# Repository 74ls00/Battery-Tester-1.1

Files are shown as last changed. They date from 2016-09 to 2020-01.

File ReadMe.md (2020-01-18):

#### Анализатор батареек и аккумуляторов
----
Анализатор батареек и аккумуляторов разрабатывался по заказу одного из импортёров элементов питания и по мотивам статей для Ф-Центра. Задача — измерение ёмкости и оценка качества батареек в разных режимах разряда, с построением детального графика и сохранением всех полученных данных для демонстрации представителям завода-производителя.
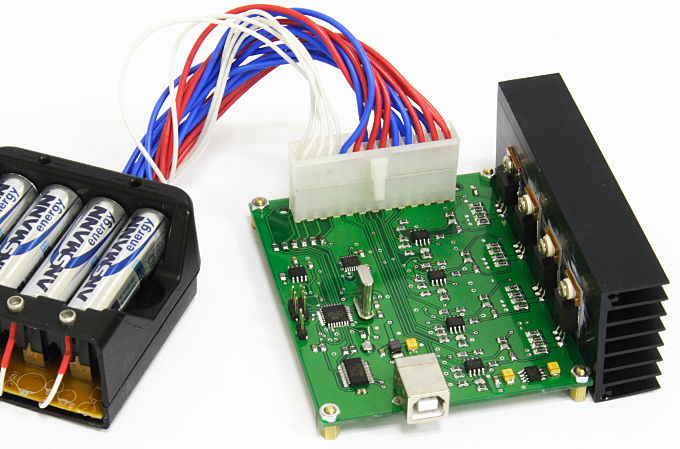
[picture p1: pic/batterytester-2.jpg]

Основные возможности стенда:

- общение с компьютером по USB, полностью программное управление;
- питание от шины USB;
- четыре независимых канала разряда с током 0…3 А каждый и шагом изменения тока 3 мА;
- режимы разряда постоянным током, постоянной мощностью (ток растёт по мере разряда) и на постоянное сопротивление (ток падает по мере разряда);
- режим разряда импульсным током с заданной скважностью;
- любые элементы питания с напряжением до 4,75 В, от батареек до литиевых аккумуляторов;
- 10-битные АЦП и ЦАП;
- индивидуальная калибровка каждого канала по току и напряжению;
- хранение калибровочных параметров в ПЗУ микроконтроллера;
- построение графика напряжения на элементах в реальном времени;
- установка допустимого уровня разряда элементов;
- автоматическое отключение разряженных элементов;
- светодиодная индикация состояния каждого элемента;
- сохранение всех полученных данных в формате CSV;
- автоматический расчёт ёмкости в ампер-часах и ватт-часах, а также внутреннего сопротивления элементов.

Программное обеспечение:

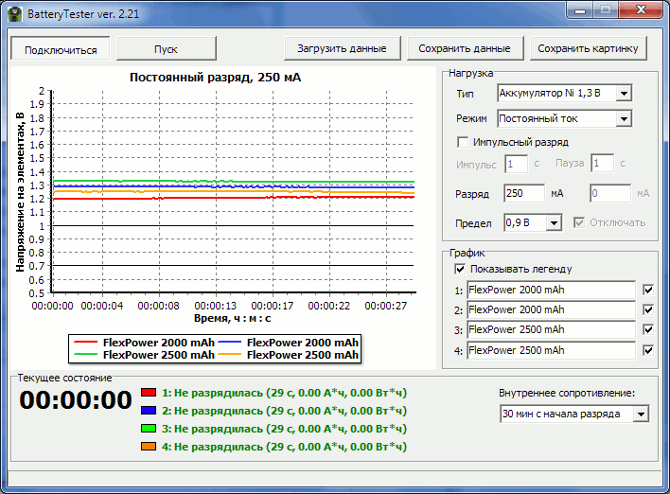
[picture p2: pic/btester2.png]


~~[Страница автора](http://olegart.ru/wordpress/batterytester/)~~

[Тема на коте](http://radiokot.ru/forum/viewtopic.php?f=11&t=135313)

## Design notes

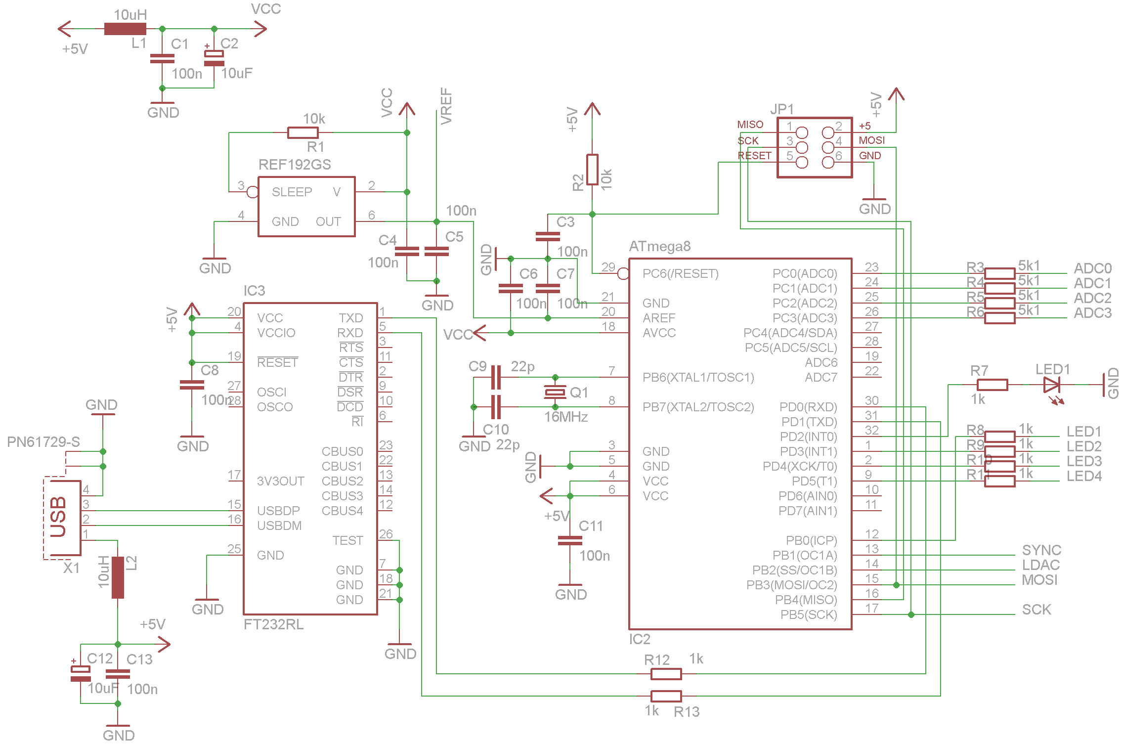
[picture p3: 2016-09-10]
hw/png/100a.png

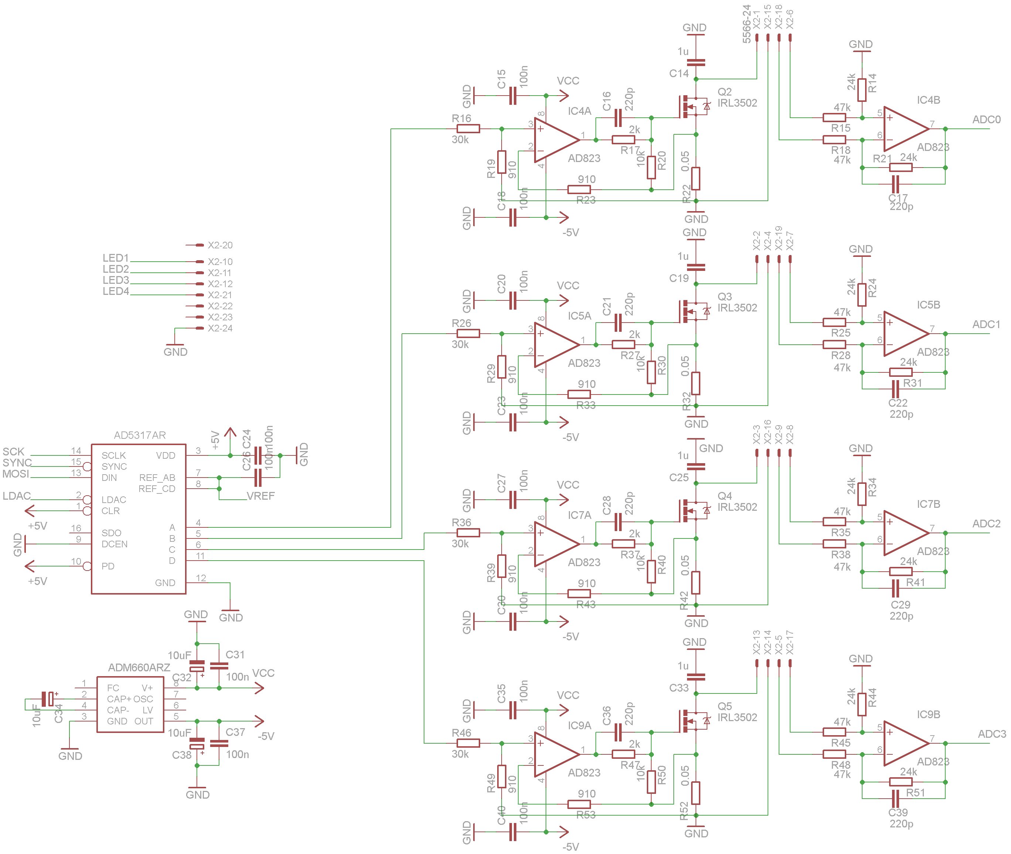
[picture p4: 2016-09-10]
hw/png/100b.png

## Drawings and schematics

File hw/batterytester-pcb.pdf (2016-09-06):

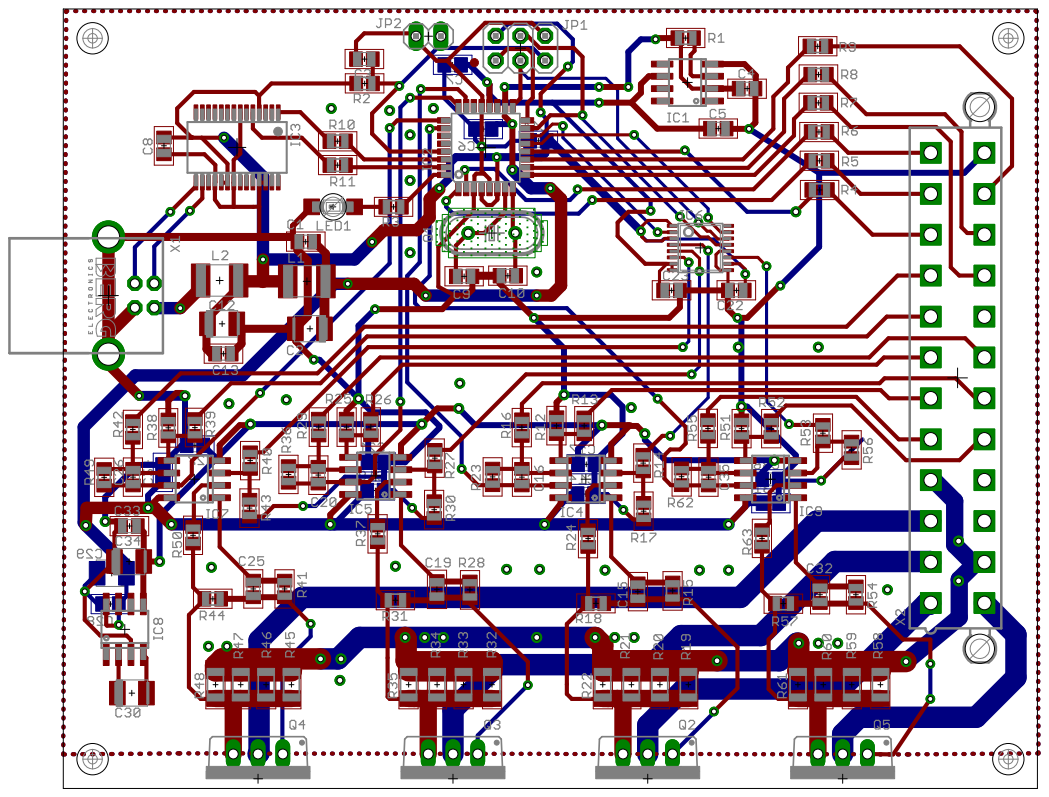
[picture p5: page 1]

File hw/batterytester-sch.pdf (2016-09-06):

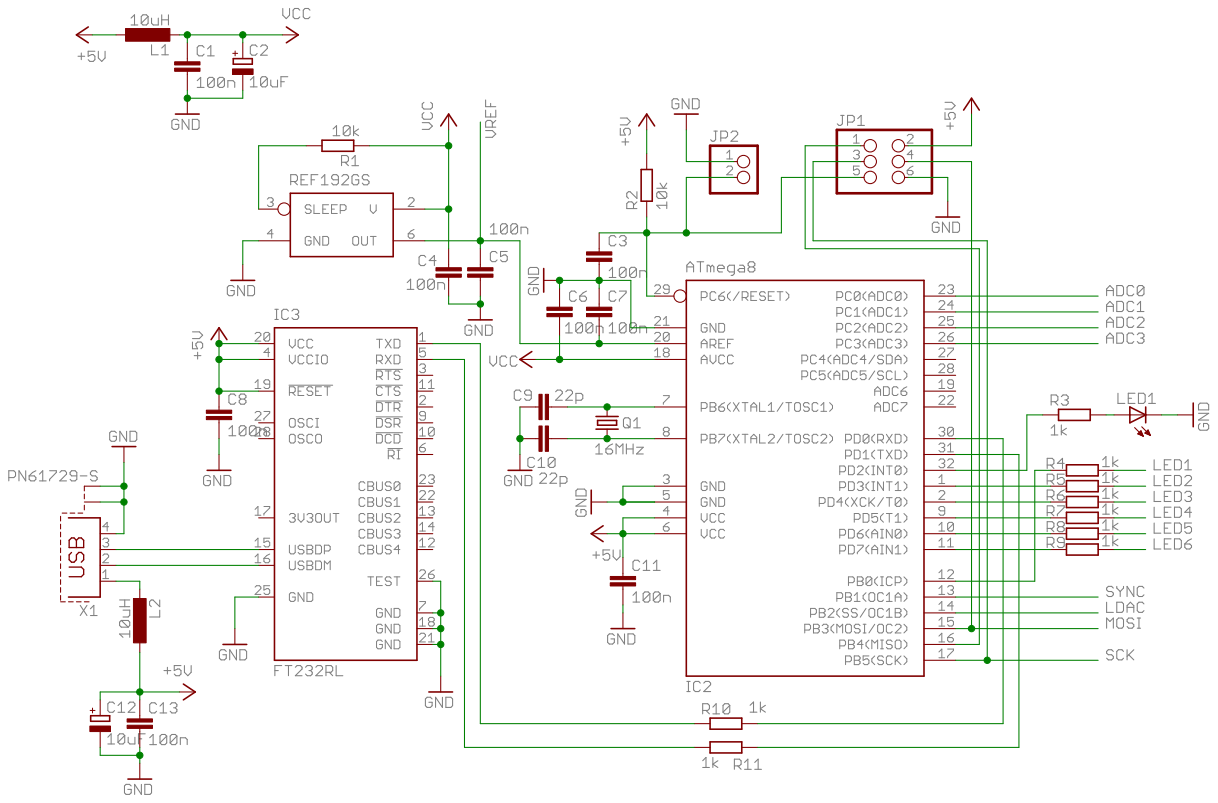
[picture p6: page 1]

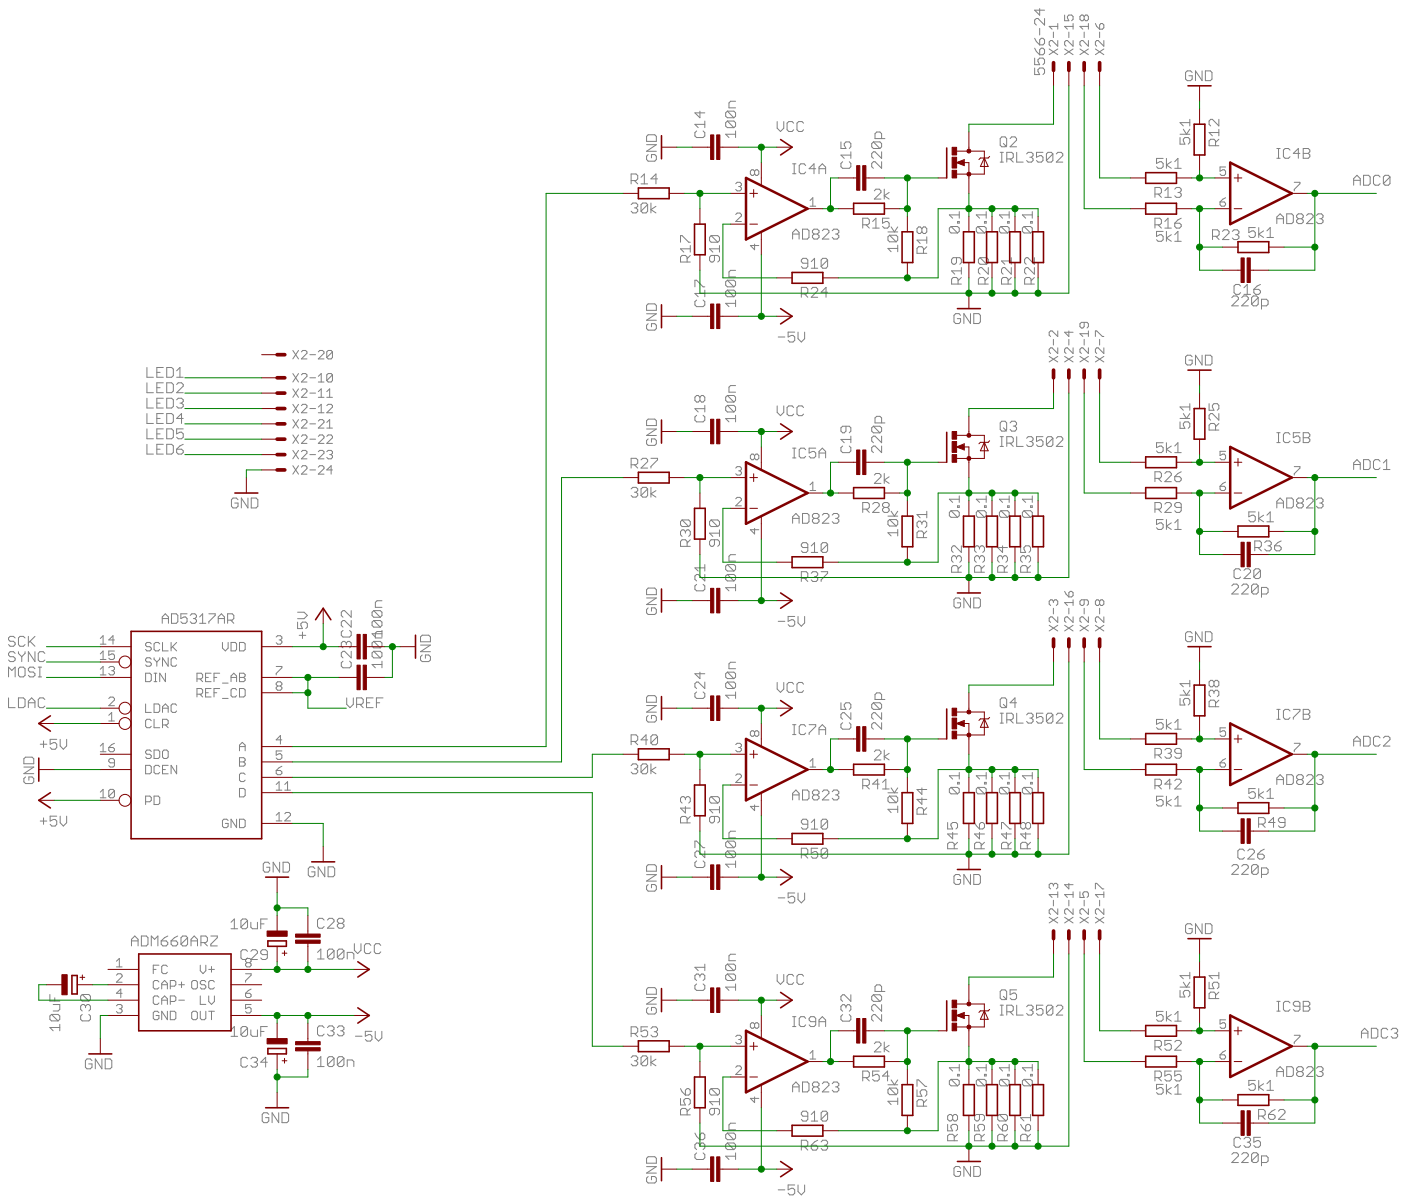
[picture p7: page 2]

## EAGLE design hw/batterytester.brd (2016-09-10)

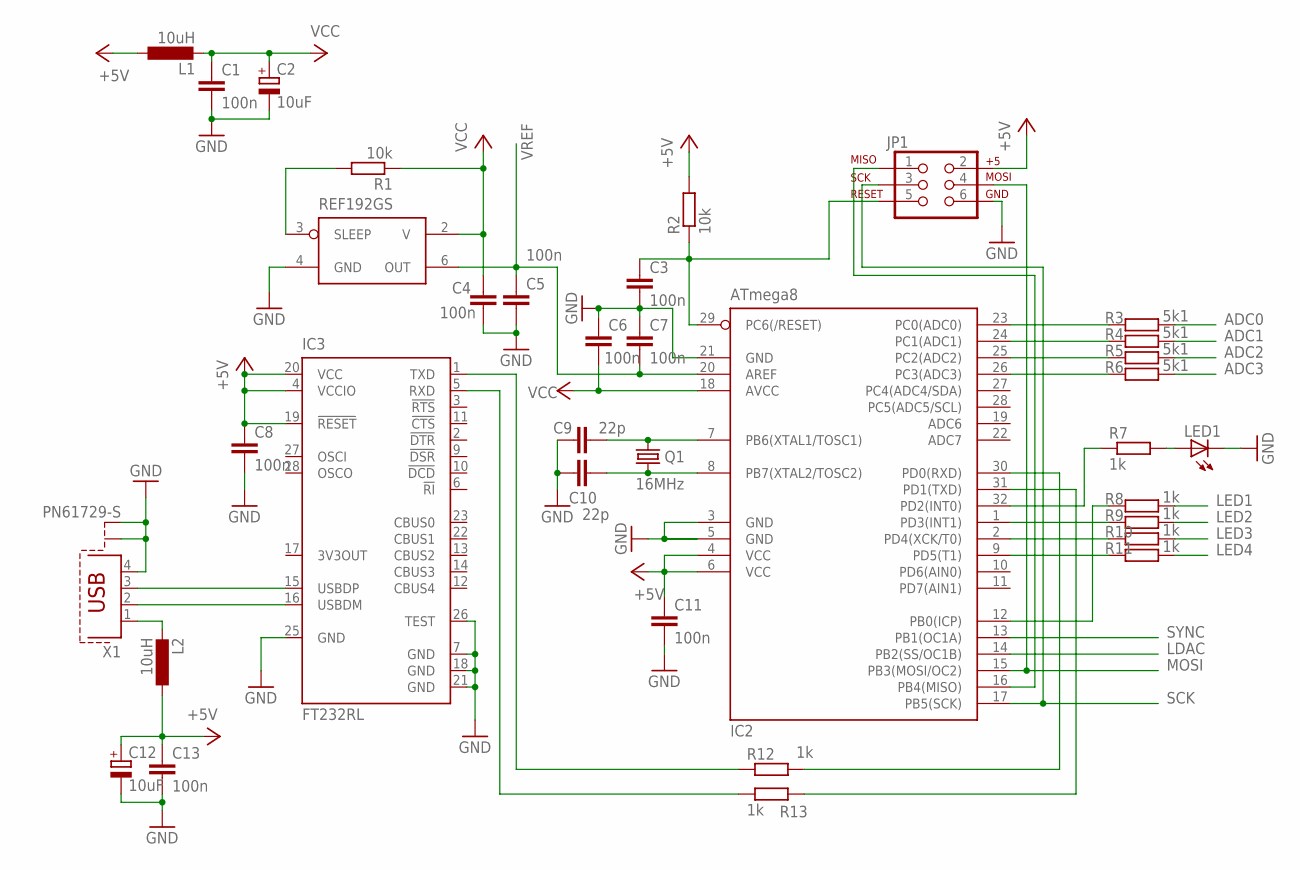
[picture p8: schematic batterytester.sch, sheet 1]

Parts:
C1, C3, C4, C5, C6, C7, C8, C11, C13: 100n; C0805
C2, C12: 10uF; SMC_B
C9, C10: 22p; C0805
IC1: REF192GS; SO8
IC2: ATmega8; TQFP32-08
IC3: FT232RL; SSOP28
JP1: AVR_SPI_PRG_6NS; 2X3-NS
L1, L2: 10uH; L1812
LED1: LED3MM
Q1: 16MHz; HC49/S
R1, R2: 10k; R0805
R3, R4, R5, R6: 5k1; R0805
R7, R8, R9, R10, R11, R12, R13: 1k; R0805
X1: PN61729-S

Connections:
+5V: C8.1, C11.1, C12.+, C13.1, IC2.4 (VCC), IC2.6 (VCC), IC3.4 (VCCIO), IC3.19 (!RESET), IC3.20 (VCC), JP1.2, L1.1, L2.1, R2.2; also elsewhere on the board
ADC0: R3.2; also elsewhere on the board
ADC1: R4.2; also elsewhere on the board
ADC2: R5.2; also elsewhere on the board
ADC3: R6.2; also elsewhere on the board
GND: C1.2, C2.-, C3.2, C4.2, C5.2, C6.1, C7.1, C8.2, C9.1, C10.1, C11.2, C12.-, C13.2, IC1.4 (GND), IC2.3 (GND), IC2.5 (GND), IC2.21 (GND), IC3.7 (GND), IC3.18 (GND), IC3.21 (GND), IC3.25 (GND), IC3.26 (TEST), JP1.6, LED1.K (C), X1.4, X1.S1, X1.S2; also elsewhere on the board
LDAC: IC2.14 (PB2(SS/OC1B)); also elsewhere on the board
LED1: R8.2; also elsewhere on the board
LED2: R9.2; also elsewhere on the board
LED3: R10.2; also elsewhere on the board
LED4: R11.2; also elsewhere on the board
MOSI: IC2.15 (PB3(MOSI/OC2)), JP1.4; also elsewhere on the board
unnamed: IC3.1 (TXD), R12.1
unnamed: IC3.5 (RXD), R13.1
unnamed: IC2.30 (PD0(RXD)), R12.2
unnamed: C9.2, IC2.7 (PB6(XTAL1/TOSC1)), Q1.1
unnamed: C10.2, IC2.8 (PB7(XTAL2/TOSC2)), Q1.2
unnamed: IC2.31 (PD1(TXD)), R13.2
unnamed: IC3.16 (USBDM), X1.2
unnamed: IC2.9 (PD5(T1)), R11.1
unnamed: C3.1, IC2.29 (PC6(/RESET)), JP1.5, R2.1
unnamed: IC2.2 (PD4(XCK/T0)), R10.1
unnamed: IC2.12 (PB0(ICP)), R8.1
unnamed: LED1.A, R7.2
unnamed: IC2.32 (PD2(INT0)), R7.1
unnamed: IC2.23 (PC0(ADC0)), R3.1
unnamed: IC3.15 (USBDP), X1.3
unnamed: L2.2, X1.1
unnamed: IC2.16 (PB4(MISO)), JP1.1
unnamed: IC1.3 (SLEEP), R1.2
unnamed: IC2.24 (PC1(ADC1)), R4.1
unnamed: IC2.25 (PC2(ADC2)), R5.1
unnamed: IC2.1 (PD3(INT1)), R9.1
unnamed: IC2.26 (PC3(ADC3)), R6.1
SCK: IC2.17 (PB5(SCK)), JP1.3; also elsewhere on the board
SYNC: IC2.13 (PB1(OC1A)); also elsewhere on the board
VCC: C1.1, C2.+, C4.1, C6.2, IC1.2 (V), IC2.18 (AVCC), L1.2, R1.1; also elsewhere on the board
VREF: C5.1, C7.2, IC1.6 (OUT), IC2.20 (AREF); also elsewhere on the board

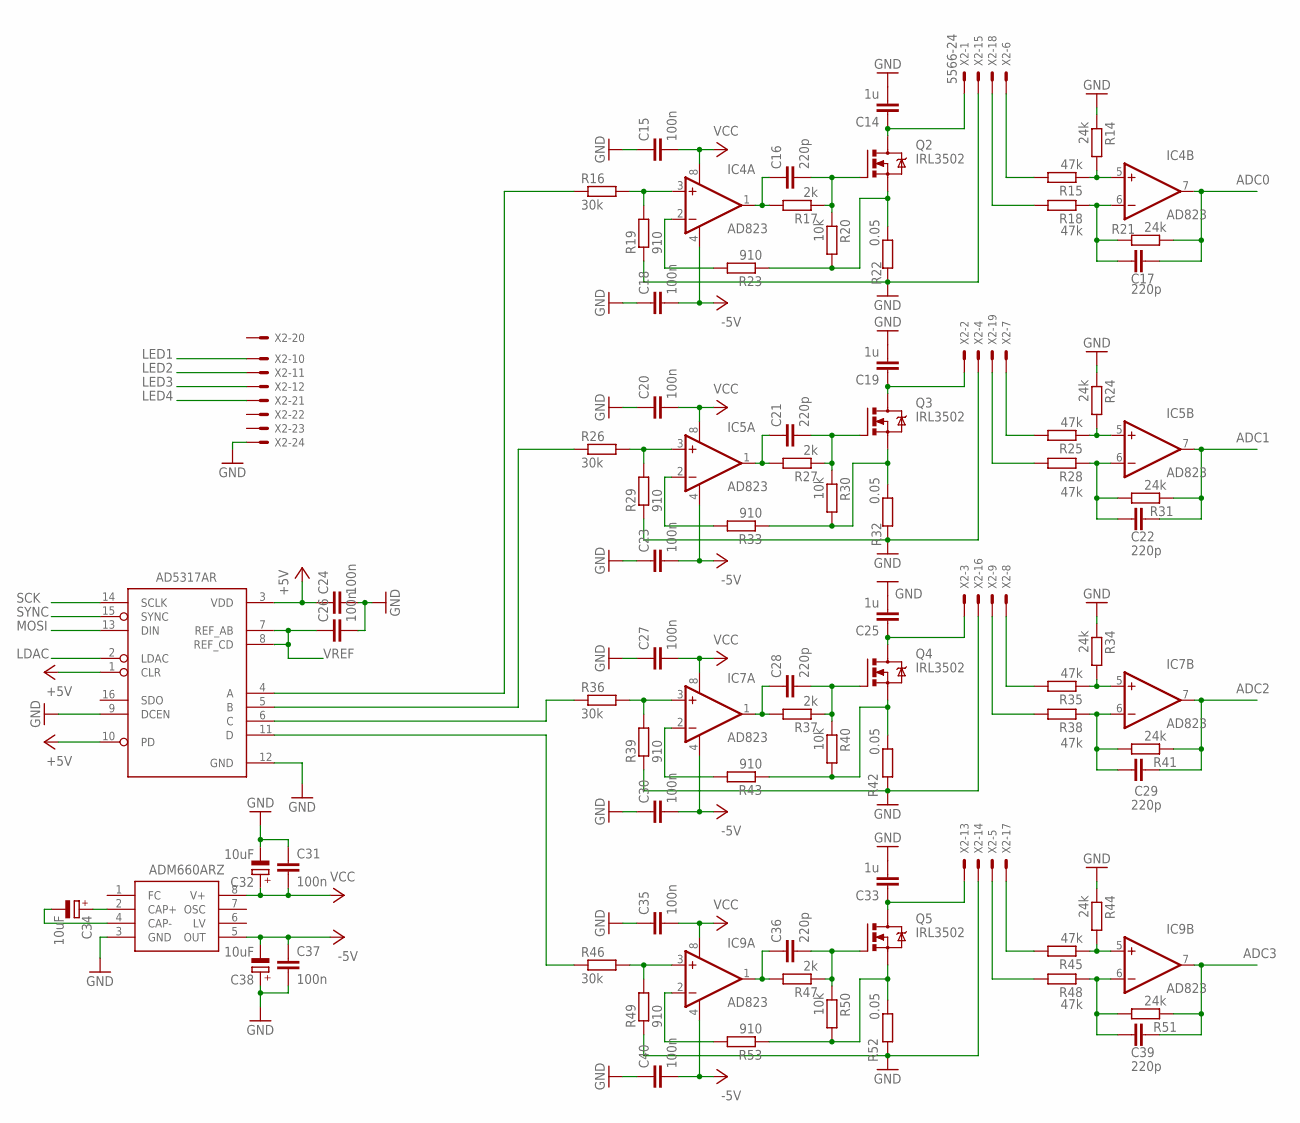
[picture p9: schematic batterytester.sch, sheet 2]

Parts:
C14, C19, C25, C33: 1u; C0805
C15, C18, C20, C23, C24, C26, C27, C30, C31, C35, C37, C40: 100n; C0805
C16, C17, C21, C22, C28, C29, C36, C39: 220p; C0805
C32, C34, C38: 10uF; SMC_B
IC4, IC5, IC7, IC9: AD823; SO8
IC6: AD5317AR; TSSOP16
IC8: ADM660ARZ; SO8
Q2, Q3, Q4, Q5: IRL3502; TO220BV
R14, R21, R24, R31, R34, R41, R44, R51: 24k; R0805
R15, R18, R25, R28, R35, R38, R45, R48: 47k; R0805
R16, R26, R36, R46: 30k; R0805
R17, R27, R37, R47: 2k; R0805
R19, R23, R29, R33, R39, R43, R49, R53: 910; R0805
R20, R30, R40, R50: 10k; R0805
R22, R32, R42, R52: 0.05; R2512
X2: 5566-24; 5569-24

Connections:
+5V: C24.1, IC6.1 (CLR), IC6.3 (VDD), IC6.10 (PD); also elsewhere on the board
-5V: C18.2, C23.2, C30.2, C37.1, C38.-, C40.2, IC4.4 (V-), IC5.4 (V-), IC7.4 (V-), IC8.5 (OUT), IC9.4 (V-)
ADC0: C17.2, IC4.7 (OUT), R21.1; also elsewhere on the board
ADC1: C22.2, IC5.7 (OUT), R31.1; also elsewhere on the board
ADC2: C29.2, IC7.7 (OUT), R41.1; also elsewhere on the board
ADC3: C39.2, IC9.7 (OUT), R51.1; also elsewhere on the board
B0: C14.1, Q2.D, X2.1
B0+: R15.2, X2.6
B0-: R18.2, X2.18
B1: C19.1, Q3.D, X2.2
B1+: R25.2, X2.7
B1-: R28.2, X2.19
B2: C25.1, Q4.D, X2.3
B2+: R35.2, X2.8
B2-: R38.2, X2.9
B3: C33.1, Q5.D, X2.13
B3+: R45.2, X2.17
B3-: R48.2, X2.5
GND: C14.2, C15.1, C18.1, C19.2, C20.1, C23.1, C24.2, C25.2, C26.2, C27.1, C30.1, C31.1, C32.-, C33.2, C35.1, C37.2, C38.+, C40.1, IC6.9 (DCEN), IC6.12 (GND), IC8.3 (GND), R14.1, R19.1, R22.2, R24.1, R29.1, R32.2, R34.1, R39.1, R42.2, R44.1, R49.1, R52.2, X2.4, X2.14, X2.15, X2.16, X2.24; also elsewhere on the board
LDAC: IC6.2 (LDAC); also elsewhere on the board
LED1: X2.10; also elsewhere on the board
LED2: X2.11; also elsewhere on the board
LED3: X2.12; also elsewhere on the board
LED4: X2.21; also elsewhere on the board
MOSI: IC6.13 (DIN); also elsewhere on the board
unnamed: IC4.3 (+IN), R16.2, R19.2
unnamed: Q2.S, R20.2, R22.1, R23.1
unnamed: Q3.S, R30.2, R32.1, R33.1
unnamed: C34.+, IC8.2 (CAP+)
unnamed: C34.-, IC8.4 (CAP-)
unnamed: IC4.2 (-IN), R23.2
unnamed: C16.1, IC4.1 (OUT), R17.2
unnamed: C16.2, Q2.G, R17.1, R20.1
unnamed: Q4.S, R40.2, R42.1, R43.1
unnamed: IC4.5 (+IN), R14.2, R15.1
unnamed: C17.1, IC4.6 (-IN), R18.1, R21.2
unnamed: Q5.S, R50.2, R52.1, R53.1
unnamed: IC5.3 (+IN), R26.2, R29.2
unnamed: IC5.2 (-IN), R33.2
unnamed: C21.1, IC5.1 (OUT), R27.2
unnamed: C21.2, Q3.G, R27.1, R30.1
unnamed: IC5.5 (+IN), R24.2, R25.1
unnamed: C22.1, IC5.6 (-IN), R28.1, R31.2
unnamed: IC7.3 (+IN), R36.2, R39.2
unnamed: IC7.2 (-IN), R43.2
unnamed: C28.1, IC7.1 (OUT), R37.2
unnamed: C28.2, Q4.G, R37.1, R40.1
unnamed: IC7.5 (+IN), R34.2, R35.1
unnamed: C29.1, IC7.6 (-IN), R38.1, R41.2
unnamed: IC9.3 (+IN), R46.2, R49.2
unnamed: IC9.2 (-IN), R53.2
unnamed: C36.1, IC9.1 (OUT), R47.2
unnamed: C36.2, Q5.G, R47.1, R50.1
unnamed: IC9.5 (+IN), R44.2, R45.1
unnamed: C39.1, IC9.6 (-IN), R48.1, R51.2
unnamed: IC6.4 (A), R16.1
unnamed: IC6.5 (B), R26.1
unnamed: IC6.6 (C), R36.1
unnamed: IC6.11 (D), R46.1
SCK: IC6.14 (SCLK); also elsewhere on the board
SYNC: IC6.15 (SYNC); also elsewhere on the board
VCC: C15.2, C20.2, C27.2, C31.2, C32.+, C35.2, IC4.8 (V+), IC5.8 (V+), IC7.8 (V+), IC8.8 (V+), IC9.8 (V+); also elsewhere on the board
VREF: C26.1, IC6.7 (REF_AB), IC6.8 (REF_CD); also elsewhere on the board

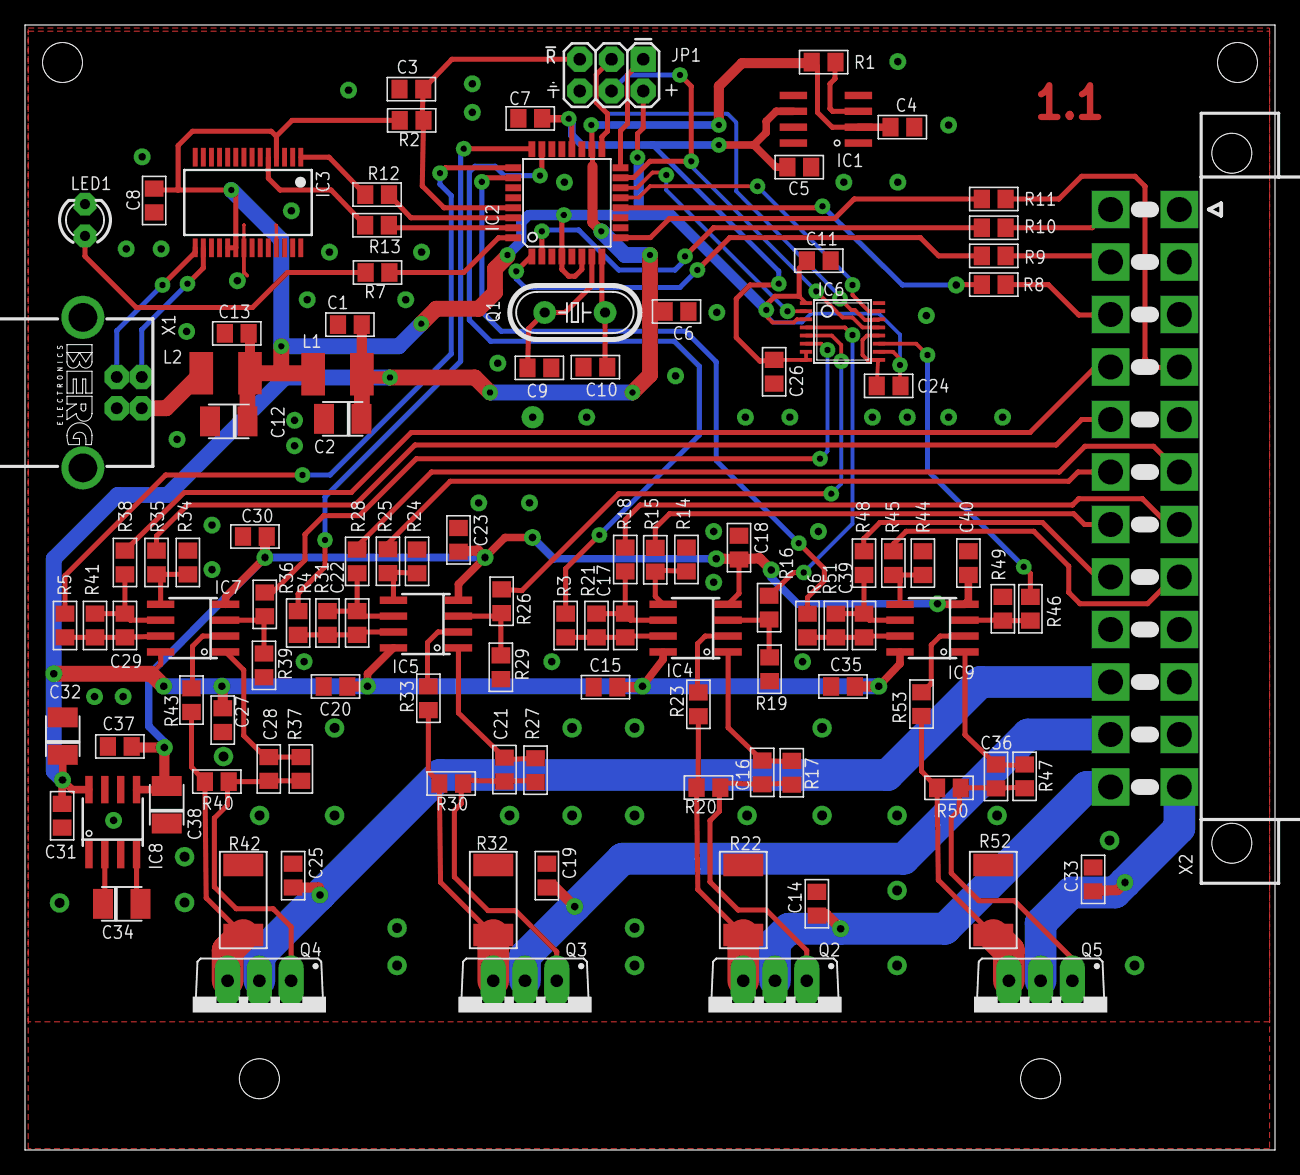
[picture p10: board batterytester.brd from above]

Board: 2 copper layers, 100.0 x 90.0 mm, 113 parts (0 on the bottom side), 85 nets.

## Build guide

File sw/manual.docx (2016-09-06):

Свежие версии программ и драйверов: http://www.fclab.ru/projects/batterytester/

Подключение установки:

- Установить драйвер USB-интерфейса.
- Подключить установку к USB-порту.
- Запустить программу btest.exe. Установки она не требует.

Установка предназначена для проведения тестирования (измерения ёмкости и внутреннего сопротивления) гальванических элементов и никелевых аккумуляторов типоразмеров AA, AAA, C и D с напряжением 1,5 В, одноразовых литиевых элементов питания с напряжением 3,0 В, батарей с напряжением до 4,5 В, а также литиевых аккумуляторов с напряжением 4,3 В. Одновременно тестируются до четырёх элементов.

Установка позволяет устанавливать и поддерживать разрядный ток до 3 А на каждый элемент, а также работать в режиме постоянной потребляемой мощности, когда разрядный ток автоматически увеличивается при падении напряжения на элементе (этот режим эмулирует поведение современной электронной аппаратуры).

Установка подключается к компьютеру по интерфейсу USB и управляется с помощью программы, работающей в среде MS Windows 2000, XP или Vista.

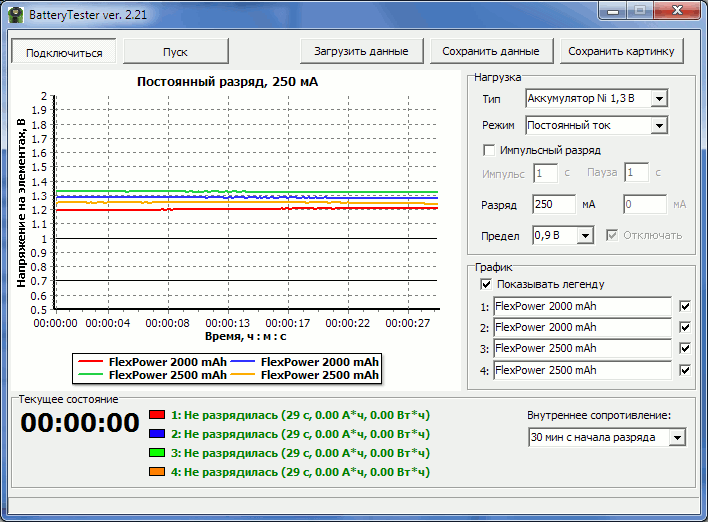
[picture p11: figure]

Работа с установкой начинается с нажатия кнопки «Подключение». После этого программа опрашивает имеющиеся USB-устройства в поисках нужного — если таковое найдётся, становится активной кнопка «Пуск». Если устройство не найдено, отключите установку от USB-порта и подключите вновь, после чего подождите около 10 секунд (это время инициализации установки после подачи питания) и снова нажмите кнопку «Подключение». После подключения к USB-порту на установке должен несколько раз мигнуть светодиод, расположенный на основной плате, а по светодиодам батарейного блока должна пробежать «волна» от первого к четвёртому — это сигнализирует об исправности процессорной части установки.

Батарейки или аккумуляторы необходимо установить в батарейный блок до запуска процесса измерений, иначе на первом же шаге установка посчитает их разряженными в ноль и отключит нагрузку.

По нажатию кнопки «Пуск» начинается собственно процесс разряда батареек с одновременным замером напряжения на них. Способ разряда задаётся в блоке «Нагрузка» справа от графика:

- «Тип» — тип аккумулятора или гальванического элемента (батареи). При выборе аккумуляторов блокируется галочка «Отключать», так как разряд аккумуляторов ниже допустимого порога (0,9—1 В для никелевых и 2,5—3 В для литиевых) приведёт к выходу их из строя.
- «Режим» — разряд постоянным током или постоянной мощностью, первый традиционно используется производителями батареек при определении их ёмкости, второй же эмулирует работу реальной современной электроники.
- «Импульсный разряд» — разряд с периодическим изменением нагрузки между двумя значениями. Такой режим разряда характерен, например, для фотовспышек; батарейки и аккумуляторы в нём могут показать немного большую ёмкость, чем при разряде постоянным током, так как у них есть дополнительно время на восстановление.
  - «Импульс», «Пауза» — длительности импульсов в секундах. Строго говоря, пауза не является паузой в полном смысле этого слова, в её течении ток нагрузки может быть отличен от нуля.
- «Разряд» — ток разряда в миллиамперах. При импульсном разряде в первом окне задайтся ток во время импульса, во втором — во время паузы (он может быть равен нулю). Если включён режим постоянной мощности, то указанное значение тока считается номинальным для напряжения элемента 1,5 В; при меньшем напряжении ток пропорционально увеличивается, при большем — уменьшается.
- «Предел» — значение напряжения, при котором элемент считается полностью разряженным. Типичная величина — 1,0 В для аккумуляторов под нагрузкой до 1 А, 0,9 В для аккумуляторов под большей нагрузкой, 0,7 В для батареек.
- «Отключать» — автоматически отключать от нагрузки элементы, напряжение на которых уменьшилось ниже предельного значения. Для аккумуляторов галочка всегда установлена.

В отдельный блок вынесены настройки отображения графика, не влияющие на измерения:

- «Показывать легенду» — показывать ли под графиком легенду с названием батареек или аккумуляторов.
- Четыре текстовых поля и галочки после них — названия тестируемых батареек. Снятие галочки вообще убирает соответствующий график с экрана.
- «Время» — максимальное время по горизонтальной оси графика.
- «Сглаживание» — сглаживание графика после окончания измерений для снижения влияния случайного шума. Рекомендуется включать.

В блоке «Текущее состояние» в процессе измерений показывается время с момента начала измерений и напряжения на каждом из четырёх элементов. После окончания измерений вместо напряжений показывается время, за которое элемент был разряжен (если он успел разрядиться до указанного предела), а также его ёмкость в ампер-часах и ватт-часах.

В строке состояния в нижней части окна программы в процессе измерений пишутся текущие установленные токи, что особенно полезно в режиме постоянной мощности, когда ток подстраивается автоматически в зависимости от напряжения на элементах.

При разряде элемента ниже порогового значения и установленной галочке «Отключать при разряде» нагрузка с него снимается (напряжение при этом может подняться обратно, но нагрузка восстановлена уже не будет), а соответствующий светодиод на батарейном блоке начинает мигать. Для Ni-MH аккумуляторов автоматическое отключение является обязательным требованием, так как снижение напряжения ниже 1,0 В может повредить их, а вот батарейки ради получения красивого графика с плавным падением напряжения до нуля можно оставить разряжаться.

При отсутствии элемента в батарейном блоке или его разряде ниже 0,05 В светодиод гаснет.

Измерения останавливаются либо по повторному нажатию кнопки «Пуск», либо после полного разряда всех элементов — автоматически.

Все режимы работы можно переключать непосредственно в ходе эксперимента. Ввод значений из числовых и текстовых полей осуществляется нажатием кнопки «Enter».

Установка измеряет напряжение на элементах с периодичностью 100 мс (10 раз в секунду), чтобы избежать переполнения графика таким объёмом данных, в процессе ихмерений он автоматически прокручивается, показывает картинку только за последние 100 секунд. После окончания измерений график показывается целиком.

В ходе работы установка автоматически сохраняет все данные в файл autosave.dat (текстовый формат CSV, разделитель — символ табуляции), которым можно воспользоваться, если в конце эксперимента случится какой-либо фатальный сбой. Кроме того, данные можно сохранить вручную в произвольный файл того же формата, а собственно график — в виде картинки формата PNG. Данные из CSV-файла можно также снова загрузить в программу для обработки. CSV-файлы также можно открывать в MS Excel и других подобных пакетах.

График можно вручную масштабировать, выделив нужную область мышкой – курсор для этого нужно вести слева направо и сверху вниз, зажав левую кнопку. Восстановление масштаба графика — движением справа налево и сверху вниз, также график будет показан в полном масштабе после загрузки сохранённого файла с данными. При сохранении графика в PNG-файл будет записана ровно та картинка, какую вы видите на экране.

Распайка разъёма подключения батарейных блоков:

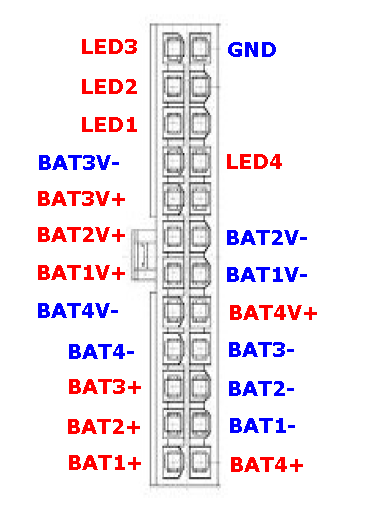
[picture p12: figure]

BAT1+…BAT4+ — «плюс» элементов питания с 1 по 4, нагрузочная линия

BAT1-…BAT4- — «минус» элементов питания с 1 по 4, нагрузочная линия

BAT1V+…BAT4V+ — «плюс» элементов питания с 1 по 4, сигнальная линия (измерение напряжения)

BAT1V-…BAT4V- — «минус» элементов питания с 1 по 4, сигнальная линия (измерение напряжения)

LED1…LED4 — аноды светодиодов батарейного блока

GND — общий катод светодиодов батарейного блока

Для соединений BAT1+…BAT4+ и BAT1-…BAT4- используются провода большого сечения, для остальных соединений сечение провода роли не играет, так как ток по ним не превышает 10 мА.

Разъём — 24-контактный Molex Mini-Fit Jr. PS-5556 (p/n 39012240), например, MF-2x12F в магазинах «Чип-и-Дип», «Платан», «Вольтмастер», MF-24F в ТД «Бурый Медведь» или Farnell артикул 4138417.

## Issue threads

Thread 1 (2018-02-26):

Chargie before testing?

sjdaliyan, 2018-02-26:
Is it possible to charge cells before testing?with this hardware

74ls00, 2018-03-08:
This possibility is not visible on the diagram.
I did not intend to design the project.

I just posted the project. Author's permission is. Details on the link to the author's page.

According to the author.
The device was assembled for service testing of batches of batteries. Was going to when he was not experienced. The project was opened several years later, after the removal of small-scale products.
Components of AD are quality and expensive, lovers do not use them, these are experienced deliveries for the plant.

You can use the translator for links with a description

sjdaliyan, 2018-03-17:
Who is the author?
vano11 ?

74ls00, 2018-03-25:
Artamonov Oleg, the first link to the author's site.
About the author http://olegart.ru/wordpress/about/

sjdaliyan, 2018-03-25:
Thanks.

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

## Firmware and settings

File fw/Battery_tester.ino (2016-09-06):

/* Battery tester */
#include <EEPROM.h>
#include <SPI.h>
//#include <MsTimer2.h>
#include <TimedAction.h>

#define MOSI 11
#define SPICLOCK 13
#define LDAC 10
#define SELECT 9

#define LED1 2
#define LED2 8
#define LED3 3
#define LED4 4
#define LED5 5
#define LED6 6
#define LED7 7

int incomingByte = 0;
int analogVal[4];
byte data[34];
unsigned long time;

TimedAction sendData = TimedAction(NO_PREDELAY, 100, ADCout);

void setup()
{  
  analogReference(EXTERNAL);
  Serial.begin(115200);
  
  // LEDs
  pinMode(LED1, OUTPUT);
  pinMode(LED2, OUTPUT);  
  pinMode(LED3, OUTPUT);
  pinMode(LED4, OUTPUT);
  pinMode(LED5, OUTPUT);
  pinMode(LED6, OUTPUT);
  pinMode(LED7, OUTPUT);
  
  // SPI
  pinMode(MOSI, OUTPUT); // MOSI
  pinMode(SPICLOCK, OUTPUT); // Clock
  pinMode(LDAC, OUTPUT); // LDAC
  digitalWrite(LDAC, HIGH);
  pinMode(SELECT, OUTPUT); // Select
  digitalWrite(SELECT, HIGH);
  SPI.mode(1 << CPHA); // send SPI data on the falling edge of SCLK
  delay(10);
  for (int i=0; i<4; i++) // write zeros to DAC
  {
    digitalWrite(SELECT, LOW); // enable DAC input register
    Spi.transfer((char)(i<<6)); // send MSB
    Spi.transfer(0);
    digitalWrite(SELECT, HIGH); // disable DAC input register    
  }
  digitalWrite(LDAC, LOW); // update DAC outputs
  delay(1); // 1 ms delay
  digitalWrite(LDAC, HIGH); // release LDAC
  
  // Timer
  // MsTimer2::set(100, ADCout); // every 100 ms
  sendData.disable();
  
  for (int l=0; l<3; l++)
  {
    digitalWrite(LED1, HIGH);
    delay(100);
    digitalWrite(LED1, LOW);
    digitalWrite(LED2, HIGH);
    delay(100);
    digitalWrite(LED2, LOW);
    digitalWrite(LED3, HIGH);
    delay(100);
    digitalWrite(LED3, LOW);
    digitalWrite(LED4, HIGH);
    delay(100);
    digitalWrite(LED4, LOW);
    digitalWrite(LED5, HIGH);
    delay(100);
    digitalWrite(LED5, LOW);
    digitalWrite(LED6, HIGH);
    delay(100);
    digitalWrite(LED6, LOW);
    digitalWrite(LED7, HIGH);
    delay(100);
    digitalWrite(LED7, LOW);
  }
}

void loop()
{
  if (Serial.available() > 1)
  {
    incomingByte = Serial.read();
    if (incomingByte == 0x55)
    {
      incomingByte = Serial.read();
      if (incomingByte == 0xAA)      
      {
        do
        {
          delayMicroseconds(1);
        }
        while (Serial.available() == 0);
        incomingByte = Serial.read();
        switch(incomingByte)
        {
        case 0x30:  // read voltages
          ADCout(); 
          break;
        case 0x31:
          setCurrent(); // set current
          break;
        case 0x32:
          setLEDs(); // enable/disable LED1...LED7
          break;
        case 0x33:  // start auto-measurements every 100 ms
          time = millis();
          sendData.enable();
          break;
        case 0x34:  // stop auto-measurements
          sendData.disable();
          break;
        case 0x40: 
          EEPROMread(); // read EEPROM
          break;
        case 0x41: 
          EEPROMwrite();  //write EEPROM
          break;
        }
      }
    }
  }
  // send ADC data every 100 ms
  sendData.check();
}

void ADCout()
{
  unsigned short i;
  for (i=0; i<4; i++)
  {
    analogVal[i] = 0;   
  } 
  for (unsigned short j=0; j<4; j++)
  { 
    for (i=0; i<4; i++)
    {
      analogVal[j] += analogRead(j);   
    }
    analogVal[j] >>= 2;
  }  
  
  Serial.print(0x55, BYTE);
  unsigned long ctime;
  ctime = millis() - time;
  for (i=0; i<4; i++)
  {
      Serial.write(lowByte(ctime));
      ctime >>= 8;
  }
  for (i=0; i<4; i++)
  {
    Serial.write(lowByte(analogVal[i]));    
    Serial.write(highByte(analogVal[i]));    
  }
}

void EEPROMread()
{
  Serial.write(0x55);
  // 1st & 2nd bytes - firmware version
  // 4 bytes - float
  // 4 channels, voltage and current, 12 bytes each channel
  // 2 + 12*4  = 50 bytes total (BLOCKSIZE)
  for (int i=0; i<50; i++)
  {
    Serial.write(EEPROM.read(i));
  }
}

void EEPROMwrite()
{
  int i = 0;
  int j = 0;
  do
  {
    if (Serial.available() > 0)
    {
      data[i] = Serial.read();
      i++;
    }
    delayMicroseconds(10);
    j++;
    if (j>10000) // 100 ms
    {
      // timeout
      Serial.write(0x31);
      return;
    }
  }
  while (i<50);
  // write received bytes to the EEPROM
  for (int j=0; j<50; j++)
  {
    EEPROM.write(j, data[j]);
  }
}

void setCurrent(void)
{
  byte i=0;
  int j=0;
  do
  {
    if (Serial.available() > 0)
    {
      data[i] = Serial.read();
      i++;
    }
    delayMicroseconds(1);
    j++;
    if (j>10000) // 10 ms timeout
    {
      return;
    }
  }
  while (i<8); // 4 channels * 2 bytes each
  
  for (i=0; i<4; i++)
  {
    data[2*i+1] += (char)(i<<6); // DAC output address - first (most significant) two bits
    digitalWrite(SELECT, LOW); // enable DAC input register
    Spi.transfer(data[2*i+1]); // send MSB
    Spi.transfer(data[2*i]); // send LSB
    digitalWrite(SELECT, HIGH); // disable DAC input register
    delayMicroseconds(100);
  }
  digitalWrite(LDAC, LOW); // update DAC outputs
  delay(1); // 1 ms delay
  digitalWrite(LDAC, HIGH); // release LDAC
}

void setLEDs(void)
{
  byte leds;
  int i=0;
  int j=0;
  do
  {
    if (Serial.available() > 0)
    {
      leds = Serial.read();
      break;
    }
    delayMicroseconds(10);
    j++;
    if (j>1000) // 10 ms
    {
      // timeout
      return;
    }
  }
  while (true); // 1 byte
  // enable/disable status LEDs
  digitalWrite(LED7, bitRead(leds, 6));
  digitalWrite(LED6, bitRead(leds, 5));
  digitalWrite(LED5, bitRead(leds, 4));
  digitalWrite(LED4, bitRead(leds, 3));
  digitalWrite(LED3, bitRead(leds, 2));
  digitalWrite(LED2, bitRead(leds, 1));
  digitalWrite(LED1, bitRead(leds, 0));
}

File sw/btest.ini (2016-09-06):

[Discharge]
Chemistry=0
Depth=1
Mode=2
Current1=0
Current2=0
Pulse=0
Duration1=1
Duration2=1
Autodisable=1
[Settings]
Left=386
Top=37
[Graph]
ShowLegend=1

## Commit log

2016-09-09 add pcb lay6
2016-09-10 add png
    [batterytester.brd]
